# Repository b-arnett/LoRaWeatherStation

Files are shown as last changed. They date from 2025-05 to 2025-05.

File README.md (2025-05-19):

# LoRaWeatherStation
## Raspberry Pi Pico 2 based, automated solar-powered weather station and 'smart' home.



This repository contains code, STL cad files, notes, and pictures for a Remote weather station and 'smart' home that I designed.  This project operates on Raspberry Pi Pico 2s and uses RYLR993 lite LoRa modules for the communication method between the weather station and model house.  The use of these modules is pretty simple with the use of AT+ commands and initial range tests showed 1000+ feet in urban environment, and 1500 feet in a rural area with strong signal strength.   

## Repo 'map'
### Each system has Code and CAD subfolders for related content

- WeatherStation folder contains all code associated with the Weather Station.  WSMainSend.py is the finalized, tested and working code.  Other files are test programs.
- SmartHouse folder contains all code associated with the Smart House.  ModelComplete.py is the finalized, tested and working code.  Other files are test programs.
- LoRaTests folder contains test code for the using RYLR993 lite lora modules with CircuitPython.
- Documents contains pictures, notebook scans, and other documentation accumulated during this projects development.
- WebServer folder has code and cad files for the additional, SeeedStudio Xiao ESP32C6 based web server that hosts a simple stats page and graph.     

### Example of how the web server displays
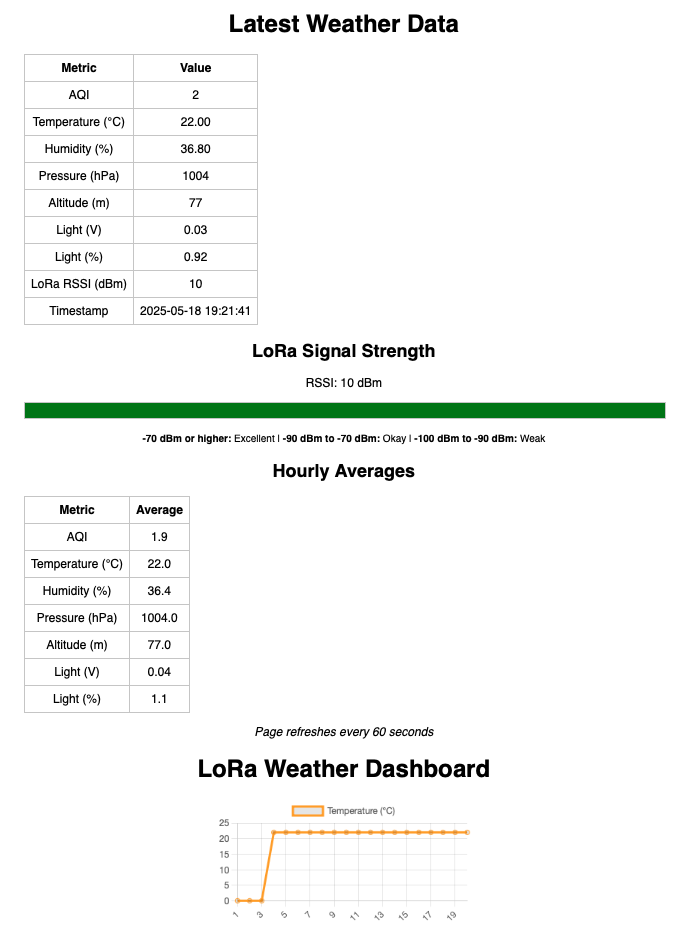
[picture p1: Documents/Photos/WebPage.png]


### To be added:
- Commenting on test programs
- Additional project documentation

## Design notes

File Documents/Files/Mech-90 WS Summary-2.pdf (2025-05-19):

Mech-0090 | Ben Arnett

### Project Summary

Issues
The first issue I encountered was converting code from MicroPython to CircuitPython. Adafruit provides CircuitPython libraries to use with a lot of their products, and for ease of use I decided to make the switch from MicroPython. While both were similar, the manner in which GPIO pins and libraries are used felt noticeably different and took some time to get used to and convert code properly. Another relatively big issue was that I prioritized the development of the Weather Station side while incrementally testing parts of the Smart House. Every component worked when individually testing them, but by the time I was testing all of the Smart House actuators together I had power supply issues due to oversight by using a standard 5V 1A outlet. With a servo, LEDs, LCD, and motor connected, the power supply was insufficient so I opted to remove the motor to prioritize getting everything else properly functioning and built. This was a huge “how did I miss that” moment and while I could have added an internal battery, it would take away from the simplicity of just plugging in a USB-C cable. With that– as it stands the measured light is the only parameter that changes physical states of the Smart Homes’ actuators (LEDs, shutters).

Unique Features
The primary unique feature employed was the use of LoRa wireless data transmission. When most people think of wireless communication, the first things that come to mind are WiFi, Bluetooth, and cellular. While these provide high bandwidths, they come at the cost of range and power consumption. As IoT (Internet of Things) devices are becoming more and more prevalent, LoRa provides an elegant solution for long range, low-power applications. While the amount of data it can transfer at a time is limited (256 bytes at a time), this is more than sufficient for applications like relaying sensor data or short messages.
Another unique feature is that the system pair is completely automated other than the need to supply / connect power. Once the solar station is up, it takes care of itself and intermittently reads and sends weather data. The Smart house, on the other hand, waits for weather data and automatically adjusts the interior controls.
One last unique feature that I added last minute was a standalone LoRa receiver and website host. This keychain-sized package is set up to connect to my phone's hotspot and host a website that displays the latest received weather data as well as the average data for the last hour. This bit runs on a SeeedStudio Xiao-ESP32C6, which has an incredibly small footprint in addition to WiFi and Bluetooth capability. Had I learned about this uC prior to starting this project, I would have likely chosen another

Mech-0090 | Ben Arnett

small form-factor board from SeeedStudio’s Xiao line of uC’s. I primarily used vibe coding (AI prompted coding) to program this, as I have no prior experience with programming on Arduino IDE with C/C++ and this was an extra system that I was curious to see if I could add to the project.

Future Changes
As far as changes I would make, it primarily boils down to the Weather Station housing. I would like to spend more time looking into different ways of making it rain-proof while still allowing for good airflow through the system. One downside of having the solar panels mounted on the roof was that it noticeably increased the temperature inside the station due to them being a dark color and absorbing heat from the sun. Another contributor to this temperature increase was likely insufficient air flow going through the station. Another “quality of life” improvement I’d make would be to adjust how the station pieces connect to each other– because of the design of how everything comes together it becomes a time consuming task for even just connecting the power inside. To go with that, the addition of a waterproof switch would make the process of turning on the station much easier.
I also want to redesign the power supply of the model house in order to use a motor for a fan. This would also allow for additional physical state changes based on things like temperature and humidity.
Further changes would be integrating the Smart Home with the internet, and LoRaWAN in general. This would make the stations’ data available from anywhere in the world, and truly make it an Internet of Things device. To go with that, adding a website host/handler directly to the smart home would be ideal instead of another separate device.

Total Cost: $496.26

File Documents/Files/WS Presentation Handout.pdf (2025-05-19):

Mech-0090 | Ben Arnett

### Weather Station and Smart Home

Project Goal:
1. Create a solar-powered, weather data acquisition system that wirelessly transmits collected data.
2. Make a smart home that receives weather data, and automatically adjusts “interior climate” settings.
How it works:
The wireless communication between systems is accomplished using LoRa, or Long Range data transmission. LoRa is a communication method that lets ‘small’ devices talk over long distances (miles with a good line of sight) and uses very little power. The weather station measures temperature, relative humidity, pressure, ambient light, particulate matter, and gas VOC. The smart home then displays the more ‘desirable’ data on an LCD character display and adjusts its interior lights and shutters.

Microcontroller / Language:
Raspberry Pi Pico 2 for UART pins to use Reyax RYLR LoRa modules with. CircuitPython. Simplified code walkthrough:
Weather Station: Read equipped sensors and format measurement values. Process those values into a formatted string, so the model house can parse the data. Send that formatted string using LoRa wireless data transmission. Go to sleep for a while, the weather typically changes at a ‘slow’ rate. Smart Home: Upon POR, modulate LEDs and Shutter servo to show they work. Wait for incoming data. Extract the payload from the incoming data string. Parse the payload into a dictionary (key:value pairs) so that it can act on the data. Change the LEDs and Shutter position. Update the LCD to display temperature, relative humidity, AQI, and light percentage. Continue waiting for incoming data. Issues encountered:
Power supply issues with the smart house– removed fan function due to time constraints. Converting code from MicroPython to CircuitPython and to that extent– learning another programming language.

Unique Features:
Complete automation– the only human interaction needed is to ‘plug it in’. Intelligent data manipulation for actuator adjustments. The use of LoRa communication, measured ranges of 1500+ feet in a rural area while still having strong signal strength. Additional device that hosts a website for weather data, showing latest data, hour averages, and a temperature chart.

Cost: $496.46
Github Repo:

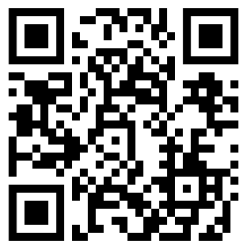
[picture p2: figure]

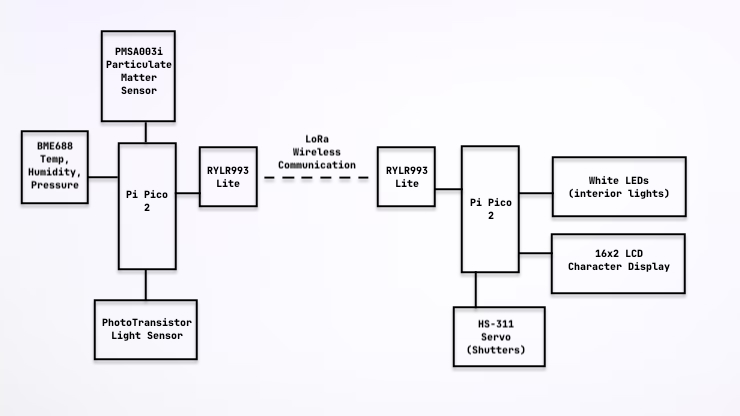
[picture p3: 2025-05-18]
Documents/Files/BlockDiagramWS.jpg

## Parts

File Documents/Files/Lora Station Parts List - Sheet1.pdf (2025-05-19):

Lora Weather Station Parts List | Ben Arnett | 05/18/25
Quantity | Description | Dist. Part No | Price Ea. | Extended Cost Running Total | Product Link | Datasheet / Reference Link

2

| Rylr993 Lora Module w/
antenna | B0B9XQ2822 | $23.00 | $46.00 | $92.00 https://www.amazon.com/REYAX-RYLR998-Interface-Antenna-Transceiver/dp/B099RM1XMG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 https://reyax.com/products/RYLR993_Lite
3 Raspberry Pi Pico 2 | 6006 | $5.00 | $15.00 | $107.00 https://www.adafruit.com/product/6006 | https://datasheets.raspberrypi.com/pico/pico-2-datasheet.pdf
| 3 5v 1.2W solar panels | 5368 | $14.95 | $44.85 | $151.85 https://www.adafruit.com/product/5368

1

| BME688 - Temp, Humidity,
| Pressure, VOC | 5046 | $19.95 | $19.95 | $171.80 https://www.adafruit.com/product/5046
1 PMSA003i Air Quality Breakout 4632 | $44.95 | $44.95 | $216.75 https://www.adafruit.com/product/4632 | https://cdn-shop.adafruit.com/product-files/4632/4505_PMSA003I_series_data_manual_English_V2.6.pdf
1 Solar Charge Controller | B07MML4YJV | $13.90 | $13.90 | $230.65 https://www.amazon.com/gp/product/B07MML4YJV/ref=ewc_pr_img_2?smid=A2EH5PO307BR7O&psc=1 https://wiki.dfrobot.com/Solar_Power_Manager_5V_SKU__DFR0559
1 5200mAh LIon Battery 3.7v | B0CP7M4MY1 | $15.49 | $15.49 | $246.14 https://www.amazon.com/gp/product/B0CP7M4MY1/ref=ppx_yo_dt_b_asin_title_o00_s00?ie=UTF8&th=1
1 440pc M3 screw set | B0BMQFHDBH | $9.99 | $9.99 | $256.13 https://www.amazon.com/gp/product/B0BMQFHDBH/ref=ewc_pr_img_5?smid=AZGB5J3DWE4QP&th=1
2 Photo Transistor | 2831 | $0.95 | $1.90 | $258.03 https://www.adafruit.com/product/2831 | https://cdn-shop.adafruit.com/product-files/2831/HW5P-1_2015__1_.pdf
| 1 Pico Terminal PiCowbell | 5907 | $12.50 | $12.50 | $270.53 https://www.adafruit.com/product/5907

1

| 22ga Solid core hookup wire
set | B09BFFJRST | $16.99 | $16.99 | $287.52 https://www.amazon.com/gp/product/B09BFFJRST/ref=ox_sc_act_title_2?smid=AMHYOXF0C8EDF&th=1
1 M/F pin header kit | B0B973QQ8P | $9.99 | $9.99 | $297.51 https://www.amazon.com/Ruibapa-Connector-Assortment-Breakaway-P-037-Kit/dp/B0B973QQ8P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
1 Solder 0.8mm 50g | B075WB98FJ | $7.19 | $7.19 | $304.70 https://www.amazon.com/gp/product/B075WB98FJ/ref=sw_img_1?smid=A25N4YN27ERTBB&th=1
1 M3 Threaded Heat Inserts | B09MTRHBRL | $10.99 | $10.99 | $315.69 https://www.amazon.com/gp/product/B09MTRHBRL/ref=ox_sc_saved_title_5?smid=A2L1PKBL5IWW8M&th=1
1 1kg PETG Filament | 33100 | 19.99 | 19.99 | $335.68 https://us.store.bambulab.com/products/petg-hf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
1 Solderable Breadboards | B09X1CV9ST | 8.99 | 8.99 | $344.67 https://www.amazon.com/dp/B09X1CV9ST?ref=ppx_yo2ov_dt_b_fed_asin_title&th=1
1 USB-C Breakout Boards | B096M2HQLK | 8.99 | 8.99 | $353.66 https://www.amazon.com/dp/B096M2HQLK?ref=ppx_yo2ov_dt_b_fed_asin_title
1 White LEDs | B07DYWC9YT | 7.19 | 7.19 | $360.85 https://www.amazon.com/dp/B07DYWC9YT?ref=ppx_yo2ov_dt_b_fed_asin_title
1 HS-311 Servo | 2589-31311S-ND | 13.49 | 13.49 | $374.34 https://www.digikey.com/en/products/detail/hitec-commercial-solutions/31311S/12148509
1 16x2 LCD char. Display | B0D2L9JHLD | 8.99 | 8.99 | $383.33 https://www.amazon.com/Interface-Backlight-Controller-Raspberry-Tinkerboard/dp/B0D2L9JHLD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
1 Dupont Connector Kit | B01EV70C78 | 6.98 | 6.98 | $390.31 https://www.amazon.com/dp/B01EV70C78?ref=ppx_yo2ov_dt_b_fed_asin_title
1 Waterproofing Spray | 52130847 | 7.98 | 7.98 | $398.29 https://www.walmart.com/ip/V-I-P-Silicone-Water-Guard-Water-Repellent-13-13-Ounces/52130847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
1 SeeedStudio Xiao ESP32C6 | 113991254 | 5.2 | 5.2 | $403.49 https://www.seeedstudio.com/Seeed-Studio-XIAO-ESP32C6-p-5884.html
1 RYLR998 LoRa Module | B099RM1XMG | 12.6 | 12.6 | $416.09 https://www.amazon.com/REYAX-RYLR998-Interface-Antenna-Transceiver/dp/B099RM1XMG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
Tax + Shipping | $80.17 | $496.26

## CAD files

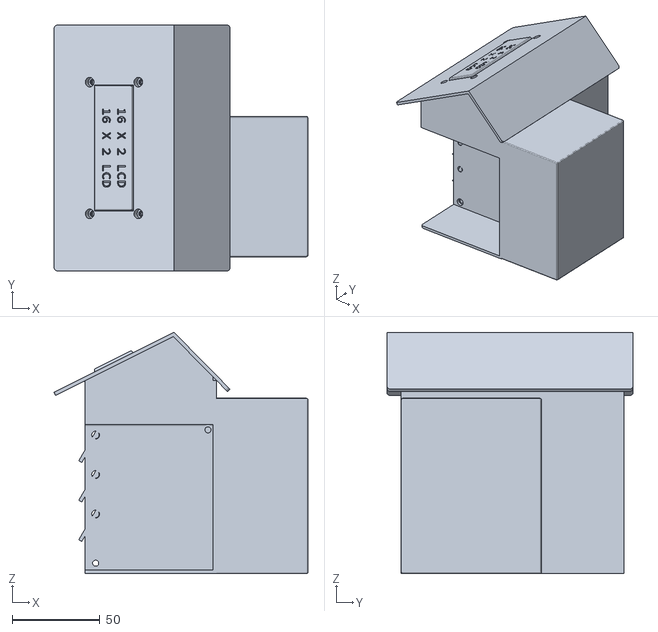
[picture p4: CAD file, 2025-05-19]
SmartHouse/CAD/ModelHouseAssembled.stl
144.7 x 140.0 x 137.6

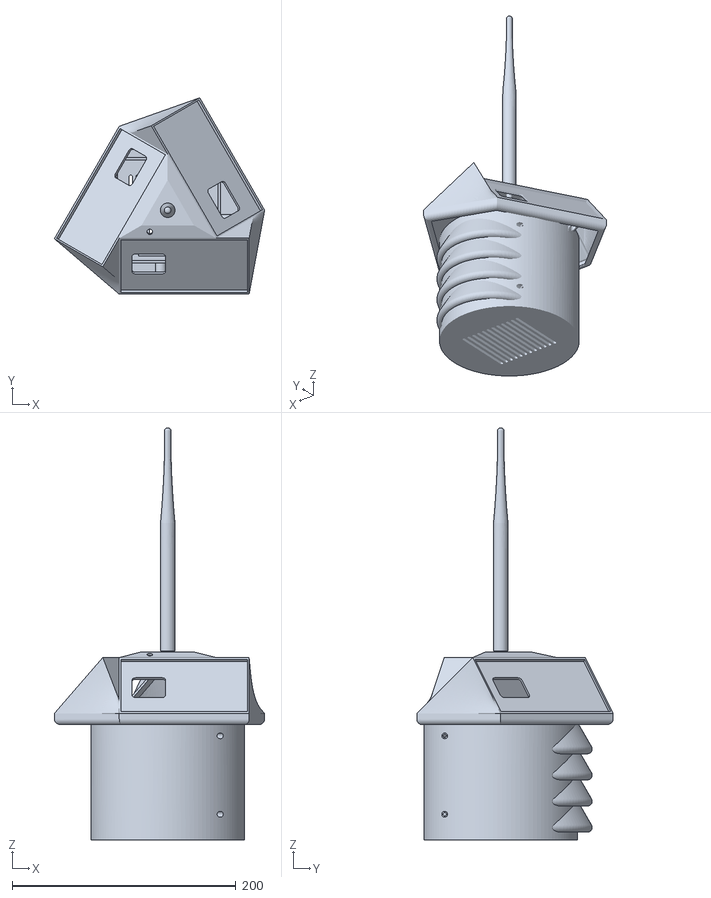
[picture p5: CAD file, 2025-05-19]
WeatherStation/CAD/WSAssembled.stl
187.9 x 175.5 x 368.0

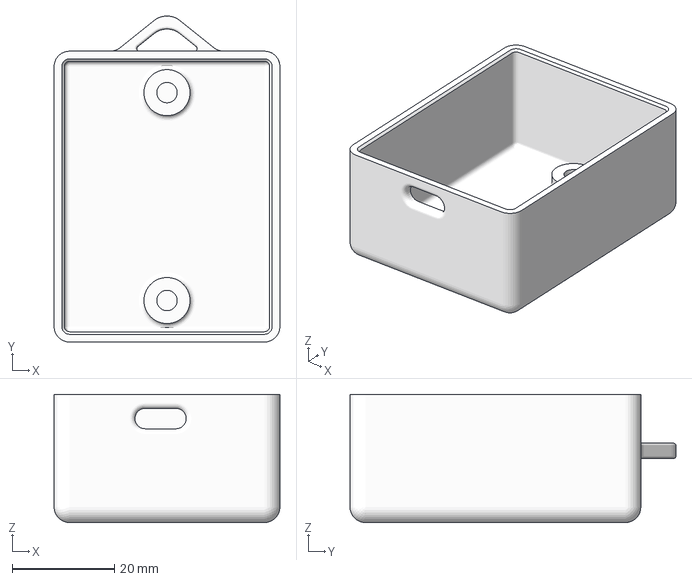
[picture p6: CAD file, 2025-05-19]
WebServer/CAD/XiaoBody.3mf
44.1 x 63.7 x 25.0 mm

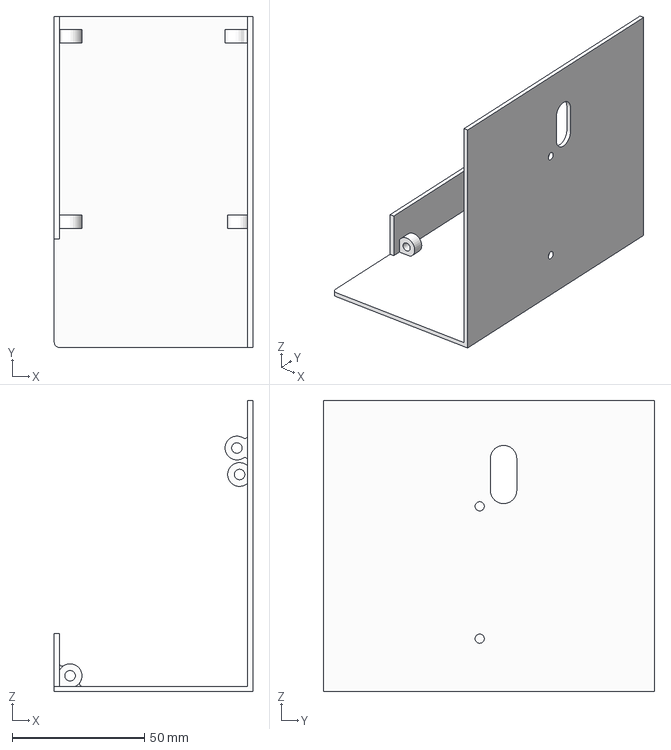
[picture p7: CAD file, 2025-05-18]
SmartHouse/CAD/ActBase.3mf
75.0 x 125.0 x 110.0 mm

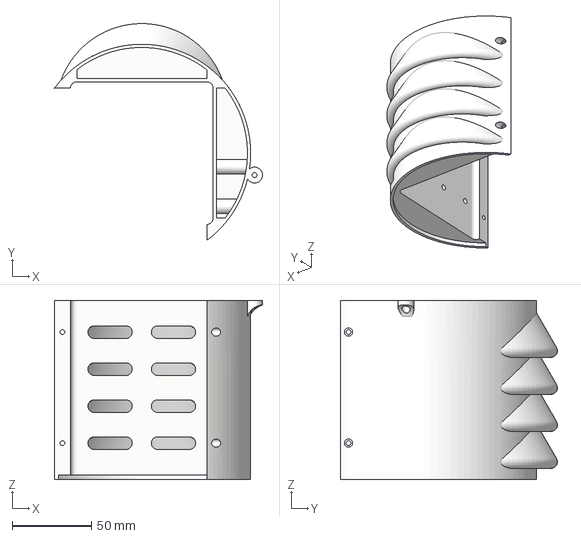
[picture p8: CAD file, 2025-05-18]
WeatherStation/CAD/WSBaseVent.3mf
131.2 x 136.8 x 113.0 mm

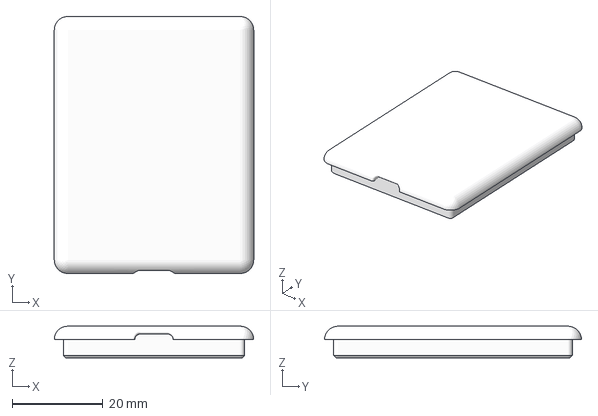
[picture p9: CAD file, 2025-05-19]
WebServer/CAD/XiaoTop.3mf
44.1 x 56.8 x 7.00 mm

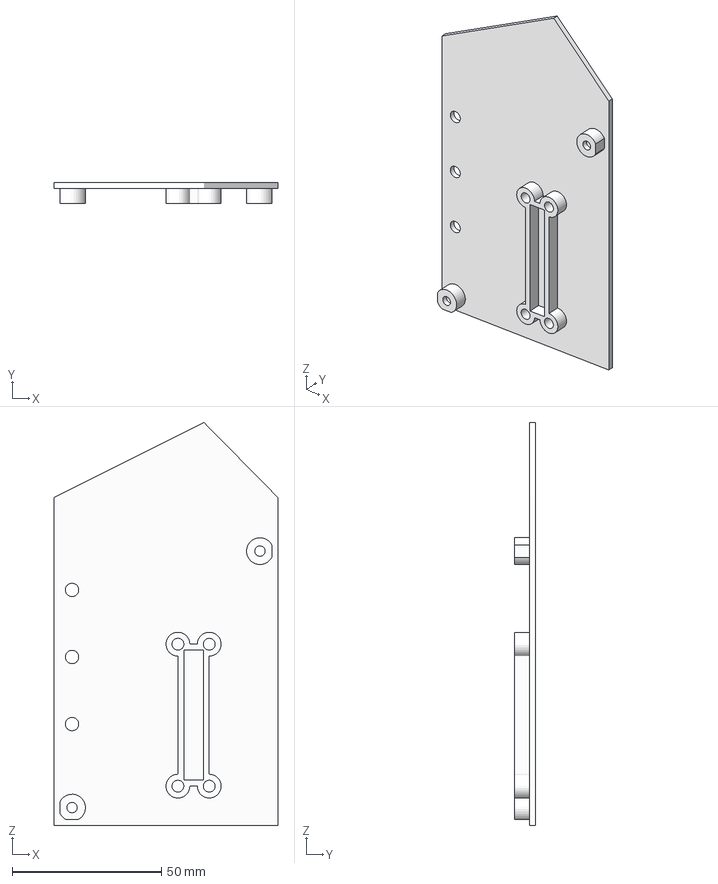
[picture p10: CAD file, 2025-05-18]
SmartHouse/CAD/AHSide.3mf
75.0 x 7.00 x 135.1 mm

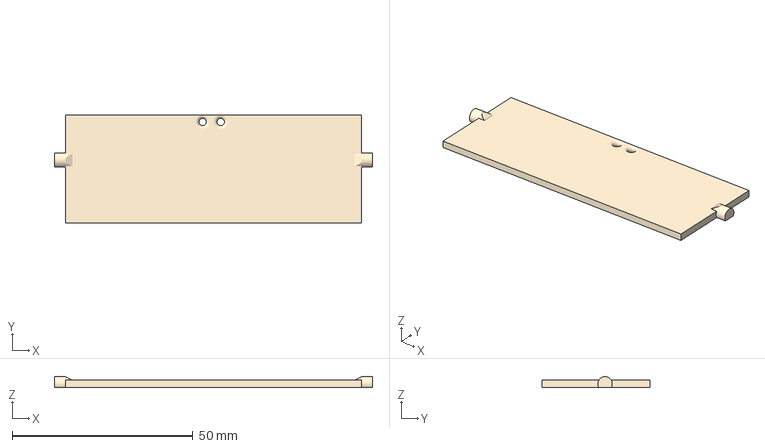
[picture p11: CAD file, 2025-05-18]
SmartHouse/CAD/ShutterPiece.3mf
88.0 x 30.0 x 3.00 mm

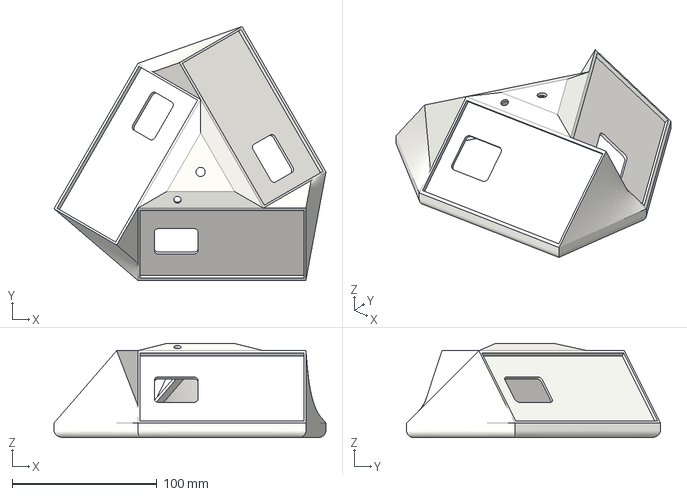
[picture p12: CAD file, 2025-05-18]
WeatherStation/CAD/WSTopRoof.3mf
187.9 x 175.5 x 65.0 mm

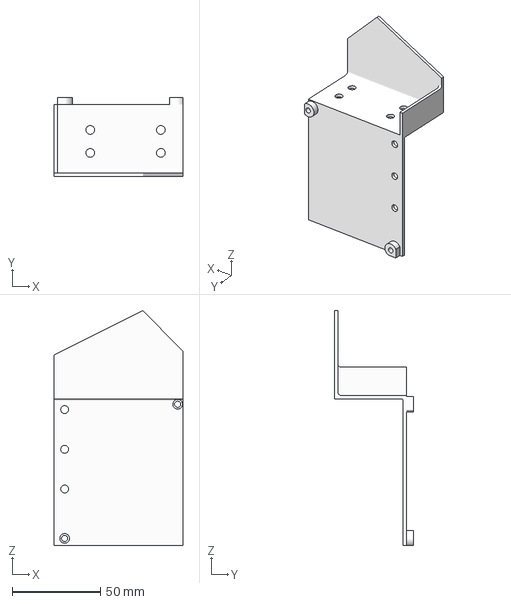
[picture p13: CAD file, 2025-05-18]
SmartHouse/CAD/LSide.3mf
73.0 x 45.0 x 133.1 mm

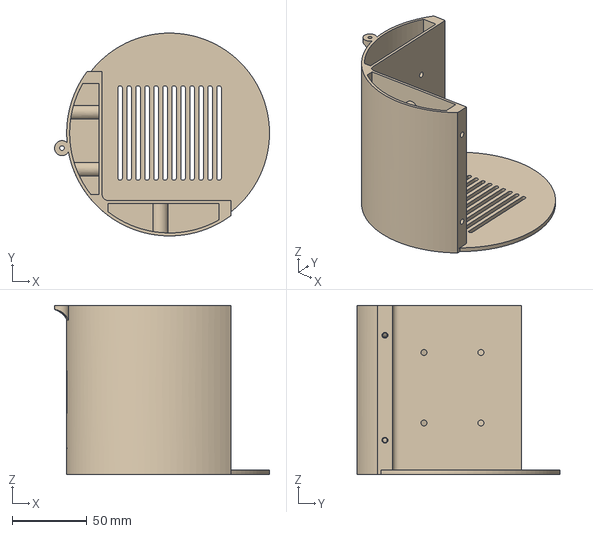
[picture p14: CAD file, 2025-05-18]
WeatherStation/CAD/WSBaseUC.3mf
143.4 x 135.3 x 113.0 mm

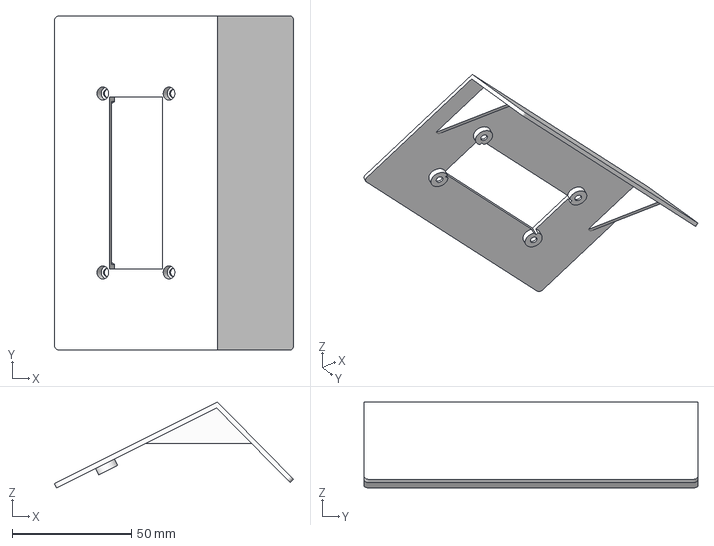
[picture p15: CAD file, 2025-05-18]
SmartHouse/CAD/Roof.3mf
100.3 x 140.0 x 36.0 mm

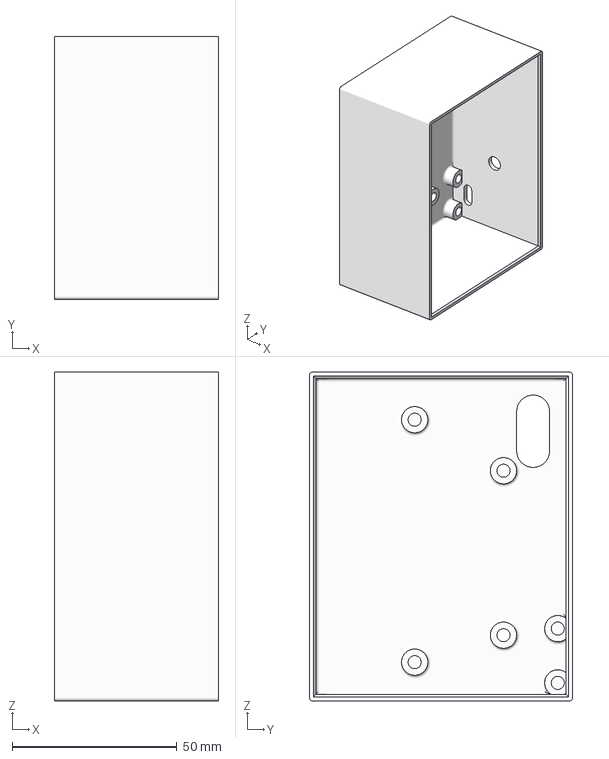
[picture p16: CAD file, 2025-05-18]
SmartHouse/CAD/ControlHousing.3mf
50.0 x 80.0 x 100.0 mm

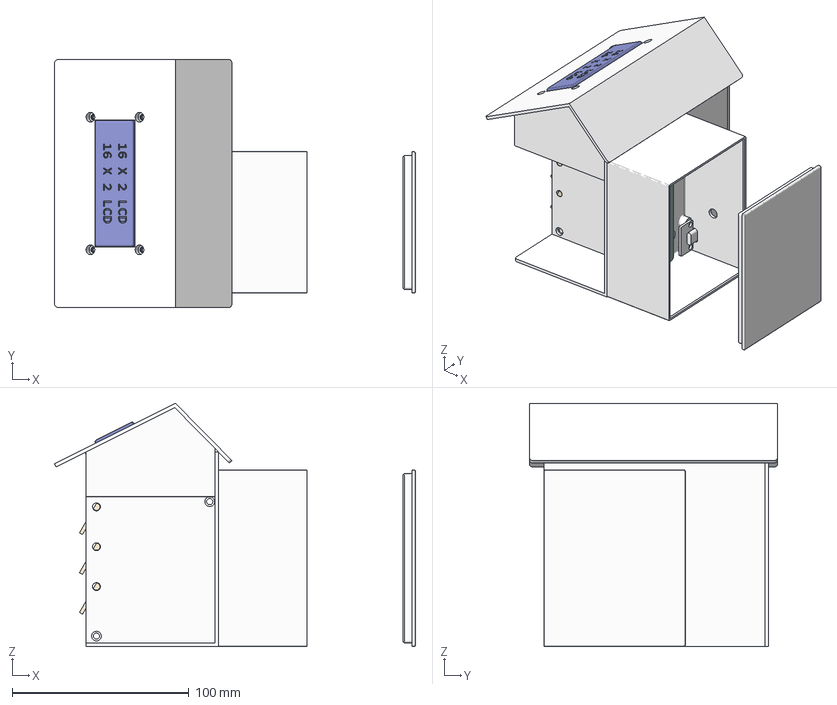
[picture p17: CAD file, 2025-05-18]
SmartHouse/CAD/Model_House_Rev_2 v15.3mf
204.0 x 140.0 x 137.6 mm

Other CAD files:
WeatherStation/CAD/WSComplete.3mf
SmartHouse/CAD/CHLid.3mf

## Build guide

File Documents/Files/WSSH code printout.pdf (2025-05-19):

# WSMainSend.py

# Ben Arnett

# 05/12/2025

import time
import board
import busio
import analogio
import adafruit_bme680
import digitalio
from digitalio import DigitalInOut, Direction, Pull from adafruit_pm25.i2c import PM25_I2C

reset_pin = None

# Setup IO pin to turn on and off PMSA03i pwr = digitalio.DigitalInOut(board.GP15) pwr.direction = digitalio.Direction.OUTPUT pwr.value = True

# Create library object, use 'slow' 100KHz frequency! i2c = busio.I2C(board.GP9, board.GP8, frequency=100000)

# Connect to a PMSA003i over I2C

pms = PM25_I2C(i2c, reset_pin) print("Found PMSA003i")

# Connect to BME688 over I2C

# note: BME688 uses the bme680 library sensor =

adafruit_bme680.Adafruit_BME680_I2C(i2c) sensor.seaLevelhPa = 1011
print("Found BME688")

# Init UART bus for RYLR993 lite

uart = busio.UART(board.GP0, board.GP1, baudrate=9600)
print("UART bus enabled")

# PhotoTransistor setup

pt = analogio.AnalogIn(board.GP26) print("Photo Transistor Found")

# Address of Rylr module to send to

address = 6

# Function to send LoRa messages with the RYLR def rylr_send(message):

length = len(message)
send = 'AT+SEND={},{},{}\r\n'.format(address, length, message)
uart.write(send.encode("ascii"))
print('Data sent to {}'.format(address))

# Function to apply AQI correction calculations def correct_pm25(pm25, humidity, temperature):

# correction calculations from ChatGPT

# Humidity correction (EPA formula) humidity_correction = 1 + 0.487 * (2.718 ** (0.059 * humidity))

pm25_corrected = pm25 / humidity_correction

# Temperature correction

temp_correction_factor = 1 - 0.02 * (temperature -25)
pm25_corrected *= temp_correction_factor

return pm25_corrected

# Get Light sensor voltage

def ptvoltage(adcin):
steps = 0
i = 0
# get average over 4 seconds while i < 20:

steps += adcin.value
time.sleep(0.2)
i += 1

steps = steps/20

# Pico ADC is 12 bits, so need to scale to 16 bits to work with CircuitPython's API

return (steps * 3.3) / 65536

# Main Loop

while True:
# Turn on PMSA, give 30s to warmup pwr.value = True

print("Turned on PMSA, 30s warmup") time.sleep(30)
print("Reading Sensors")

try:
aqdata = pms.read()
# print(aqdata)

except RuntimeError:
print("Unable to read from sensor, retrying...") continue

# get raw PM 2.5 concentration and apply corrections

pms_data = pms.read()
pm25_raw = pms_data["pm25 standard"] pm25_corrected = correct_pm25(pm25_raw, humidity, temperature)

# get BME688 sensor data

humidity = sensor.relative_humidity temperature = sensor.temperature pressure = sensor.pressure altitude = sensor.altitude

# get PhotoTransistor Voltage

ptvolt = ptvoltage(pt)

# Apply significant figures

pm25_corrected = round(pm25_corrected) humidity = "{:2.1f}".format(humidity) temperature = round(temperature) # 3 Digits pressure = round(pressure) #
altitude = round(altitude)
ptvolt = "{:1.2f}".format(ptvolt) # 3 dig. 4 char

# format to be parse-able

rylrmsg =
'AQI:{0};T:{1};RH:{2};hPa:{3};Alt:{4};L:{5}'.format(pm2 5_corrected, temperature, humidity, pressure, altitude, ptvolt)
rylr_send(rylrmsg)
print(rylrmsg)

# Turn off PMSA

pwr.value = False
print("Turned off PMSA, light sleeping")
# Light sleep till next reading time.sleep(866) # Sleep 14m 26s (15 mins between data transmissions)

# ^ account for 30s PMSA on time & 4s light volt reading

# ModelComplete.py

# Ben Arnett

# 05/12/2025

# UART = GP 0,1

# I2C = SDA-GP8, SCL-GP9

# Led PWM = GP5

# Servo PWM = GP28

import board
import busio
import digitalio
import time
import pwmio
from lcd1602 import LCD1602
from adafruit_motor import servo

# Initialize Devices

rylr = busio.UART(board.GP0, board.GP1, baudrate=9600)
i2c0 = busio.I2C(board.GP9, board.GP8, frequency=100000)

lcd = LCD1602(i2c0)
lcd.clear()
lcd.write(' Initializing')

whtled = pwmio.PWMOut(board.GP3, frequency=5000, duty_cycle=0) servo_a_pin = pwmio.PWMOut(board.GP28, frequency=50)
servo_a = servo.Servo(servo_a_pin, min_pulse=1000, max_pulse=2000)

# 'Breathe' leds once, modulate servo to verify function

for i in range(100):
if i < 50:
whtled.duty_cycle = int(i * 2 * 65535 / 100) # Up
else:
whtled.duty_cycle = 65535 - int((i - 50) * 2 * 65535 / 100) # Down
time.sleep(0.025)

whtled.duty_cycle = 0

servo_a.angle = 0
time.sleep(0.5)
servo_a.angle = 20
time.sleep(0.5)
servo_a.angle = 40
time.sleep(0.5)
servo_a.angle = 60
time.sleep(0.5)
servo_a.angle = 70
time.sleep(0.5)

lcd.clear()
lcd.set_cursor(2, 0)
lcd.write('Waiting for')
lcd.set_cursor(2, 1)
lcd.write('Weather Data')
print("Init complete, waiting for data")

recieved = False

# Function to parse new recieved data

# Modified for circuitpython from https://github.com/TimHanewich/MicroPython-Collection/blob/master/REYAX-RYLR998/

def parse_sensor_data(data: str) -> dict:
# Extract the weather data from entire recieved byte data

result = {}
address:int = None # the address of the transmitter it came from
length:int = None # the length (number of bytes) of the data payload
msg:bytes = None # the payload data itself RSSI:int = None # Received signal strength indicator
SNR:int = None # Signal-to-noise ratio

try:
# find landmarkers that will help with parsing i_equal:int = data.find("=")

i_comma1:int = data.find(",")

i_comma2:int = data.find(",", i_comma1 + 1) i_comma4:int = data.rfind(",") # search from end
i_comma3:int = data.rfind(",", 0, i_comma4-1) # search for a comma from right, starting at 0 and ending at the last comma (or right before it)
# i_linebreak:int = data.find("\r\n")

# extract

ReceivedMessage = data
address = int(data[i_equal + 1:i_comma1]) length = int(data[i_comma1 + 1:i_comma2]) msg = data[i_comma2 + 1:i_comma3] RSSI = int(data[i_comma3 + 1:i_comma4]) #SNR = int(data[i_comma4 + 1:i_linebreak]) except Exception as e:
raise Exception("Unable to parse line '" + str(data) + "' as a ReceivedMessage! Exception message: " + str(e))

# Take the weather data string and turn into a dictionary

# Modified from ChatGPT generated code pairs = msg.split(";") # Split the string into key-value pairs

for pair in pairs:
if ":" in pair:
key, value = pair.split(":") # Separate key and value
# Try to convert value to int or float if possible

if value.replace(".", "", 1).isdigit():
value = float(value) if "." in value else int(value)
result[key] = value
return result # returns a dictionary

# Function to change interior conditions

def interior(d):
light = d['L']
# If its pretty bright, open blinds and turn off lights if light > 3:

whtled.duty_cycle = 0
servo_a.angle = 15
return

involt = 3 - light
lightduty = round(involt * 18000) # inverted scaling servangle = round(18 * involt) + 15 # regular scaling

print('lightduty = {0} servangle = {1}'.format(lightduty, servangle))

whtled.duty_cycle = lightduty servo_a.angle = servangle
return

# Function to update stats on display def lcddisplay(d):

if recieved == False:
lcd.clear()
lcd.write('T: C Light: %') lcd.set_cursor(0, 1)
lcd.write('AQI: RH: %')

lightperc = round(d['L'] / 3.2 * 100)

lcd.set_cursor(2, 0)
if d['T'] < 10:
lcd.write(" ")
lcd.write(str(d['T']))
lcd.set_cursor(12, 0)
lcd.write(lcdform(lightperc)) lcd.set_cursor(4, 1)
lcd.write(lcdform(d['AQI'])) lcd.set_cursor(11, 1)
lcd.write(str(lcdform(round(d['RH'])))) return
# T:00C Light:00%

# _AQI:000 RH:00%

# Format data to write properly def lcdform(number):

stringout = ""
if number < 10:
stringout = stringout + " "
elif number < 100:
stringout = stringout + " " stringout = stringout + str(number) return stringout

# Main Loop

while True:
data = rylr.read()

if data is not None:
# Make a string with incoming data, then put it through the parser

data_string = ''.join([chr(b) for b in data]) print(data_string, end="")
parsed = parse_sensor_data(data_string) print(parsed)

# Update display and Interior settings lcddisplay(parsed)

interior(parsed)
recieved = True

else:
if recieved == False:
time.sleep(0.05)

Test Codes:
Reyax RYLR Lora Module Tests: # RYLR Receive test
import board
import busio
import digitalio
import time

led = digitalio.DigitalInOut(board.LED) led.direction = digitalio.Direction.OUTPUT

uart = busio.UART(board.GP0, board.GP1, baudrate=9600)

while True:
data = uart.read()

if data is not None:
led.value = True
data_string = ''.join([chr(b) for b in data]) print(data_string, end="")

led.value = False

else:

print("waiting")
time.sleep(0.05)

# RYLR send test

import board
import busio
import digitalio
import time

uart = busio.UART(board.GP0, board.GP1, baudrate=9600)
test = 0
send = "AT+SEND=6,4,test\r\n"

led = digitalio.DigitalInOut(board.LED) led.direction = digitalio.Direction.OUTPUT ledState = False

while True:
led.value = True

uart.write(send.encode("ascii")) print("sent")
time.sleep(2.5)
led.value = False
time.sleep(2.5)

# Rylr993RangeTest.py

# Ben Arnett

# 03/04/25

import time
import board
import busio
import digitalio

# Only use with Rylr993 lite, not 998

rylr = busio.UART(board.GP0, board.GP1, baudrate=9600)

# address of Rylr on network to send to addr = 27

led = digitalio.DigitalInOut(board.LED) led.direction = digitalio.Direction.OUTPUT

i = 1

while True:
led.value = True
msg = "Test " + str(i)
length = len(msg)
send = 'AT+SEND={},{},{}\r\n'.format(addr, length, msg)

rylr.write(send.encode("ascii")) print("Just sent test " + str(i))
led.value = False
time.sleep(5)
i += 1

Weather Station Test code

# BME688 Test from Adafruit

import board
import busio
import adafruit_bme680
import time

i2c = busio.I2C(board.GP9, board.GP8) sensor =
adafruit_bme680.Adafruit_BME680_I2C(i2c)

sensor.seaLevelhPa = 1011

while True:

print('Temperature: {} degrees C'.format(sensor.temperature))
print('Gas: {} ohms'.format(sensor.gas)) print('Humidity: {}%'.format(sensor.humidity)) print('Pressure:
{}hPa'.format(sensor.pressure)) print('Altitude: {}
meters'.format(sensor.altitude)) print("---------------------------------") time.sleep(1)

# PMSA003i test from Adafruit

# SPDX-FileCopyrightText: 2021 ladyada for Adafruit Industries

# SPDX-License-Identifier: MIT

"""
Example sketch to connect to PM2.5 sensor with either I2C or UART.
"""

# pylint: disable=unused-import

import time
import board
import busio
import adafruit_bme680
from digitalio import DigitalInOut, Direction, Pull from adafruit_pm25.i2c import PM25_I2C

reset_pin = None
# If you have a GPIO, its not a bad idea to connect it to the RESET pin

# reset_pin = DigitalInOut(board.G0)

# reset_pin.direction = Direction.OUTPUT # reset_pin.value = False

# For use with a computer running Windows: # import serial

# uart = serial.Serial("COM30", baudrate=9600, timeout=1)

# For use with microcontroller board:

# (Connect the sensor TX pin to the board/computer RX pin)

# uart = busio.UART(board.TX, board.RX, baudrate=9600)

# For use with Raspberry Pi/Linux:

# import serial

# uart = serial.Serial("/dev/ttyS0", baudrate=9600, timeout=0.25)

# For use with USB-to-serial cable: # import serial

# uart = serial.Serial("/dev/ttyUSB0", baudrate=9600, timeout=0.25)

# Connect to a PM2.5 sensor over UART

# from adafruit_pm25.uart import PM25_UART # pm25 = PM25_UART(uart, reset_pin)

# Create library object, use 'slow' 100KHz frequency!

i2c = busio.I2C(board.GP9, board.GP8, frequency=100000)
# Connect to a PM2.5 sensor over I2C pm25 = PM25_I2C(i2c, reset_pin)

sensor =
adafruit_bme680.Adafruit_BME680_I2C(i2c)

sensor.seaLevelhPa = 1011

print("Found PM2.5 sensor, reading data...")

while True:
time.sleep(1)

try:
aqdata = pm25.read()
# print(aqdata)

except RuntimeError:
print("Unable to read from sensor, retrying...")
continue

print()
print("Concentration Units (standard)") print("---------------------------------------") print(
"PM 1.0: %d\tPM2.5: %d\tPM10: %d" % (aqdata["pm10 standard"], aqdata["pm25 standard"], aqdata["pm100 standard"])
)
print("Concentration Units (environmental)") print("---------------------------------------")
print(
"PM 1.0: %d\tPM2.5: %d\tPM10: %d"
% (aqdata["pm10 env"], aqdata["pm25 env"], aqdata["pm100 env"])
)
print("---------------------------------------") print("Particles > 0.3um / 0.1L air:", aqdata["particles 03um"])
print("Particles > 0.5um / 0.1L air:", aqdata["particles 05um"])
print("Particles > 1.0um / 0.1L air:", aqdata["particles 10um"])
print("Particles > 2.5um / 0.1L air:", aqdata["particles 25um"])
print("Particles > 5.0um / 0.1L air:", aqdata["particles 50um"])
print("Particles > 10 um / 0.1L air:", aqdata["particles 100um"]) print("---------------------------------------")

print('Temperature: {} degrees C'.format(sensor.temperature))
print('Gas: {} ohms'.format(sensor.gas)) print('Humidity: {}%'.format(sensor.humidity))

print('Pressure:
{}hPa'.format(sensor.pressure)) print('Altitude: {}
meters'.format(sensor.altitude)) print("---------------------------------")

# AQI with BME688 based correction factors # From ChatGPT, with adjustments made by Ben A.

import time
import board
import busio
import adafruit_bme680 # Works for BME688 too
import adafruit_pm25
from digitalio import DigitalInOut, Direction, Pull from adafruit_pm25.i2c import PM25_I2C

# Initialize I2C communication and the PMSA003I sensor

i2c = busio.I2C(board.GP9, board.GP8, frequency=100000)
# Connect to a PM2.5 sensor over I2C pms = PM25_I2C(i2c)

# Initialize BME688 sensor

bme =
adafruit_bme680.Adafruit_BME680_I2C(i2c)

def correct_pm25(pm25, humidity, temperature):
"""
Applies correction factors to PM2.5 based on humidity and temperature.

Args:
pm25 (float): Raw PM2.5 measurement (µg/m³)
humidity (float): Relative humidity (%) temperature (float): Temperature (°C)

Returns:
float: Corrected PM2.5 value
"""
# Humidity correction (EPA formula)

humidity_correction = 1 + 0.487 * (2.718 ** (0.059 * humidity))
pm25_corrected = pm25 /
humidity_correction

# Temperature correction

temp_correction_factor = 1 - 0.02 * (temperature - 25)
pm25_corrected *= temp_correction_factor

return pm25_corrected

while True:
# Read sensor data

pms_data = pms.read()
pm25_raw = pms_data["pm25 standard"]

humidity = bme.relative_humidity temperature = bme.temperature

# Apply correction

pm25_corrected = correct_pm25(pm25_raw, humidity, temperature)

# Print results

print(f"PM2.5 Raw: {pm25_raw:.2f} µg/m³") print(f"PM2.5 Corrected:
{pm25_corrected:.2f} µg/m³") print(f"Temperature: {temperature:.2f} °C, Humidity: {humidity:.2f} %")
print("-" * 40)

time.sleep(10)

# AQI with BME688 based correction factors # From ChatGPT, with adjustments made by Ben A.

import time
import board
import busio
import adafruit_bme680 # Works for BME688 too
import adafruit_pm25
from digitalio import DigitalInOut, Direction, Pull from adafruit_pm25.i2c import PM25_I2C

# Initialize I2C communication and the PMSA003I sensor

i2c = busio.I2C(board.GP9, board.GP8, frequency=100000)
# Connect to a PM2.5 sensor over I2C pms = PM25_I2C(i2c)

# Initialize BME688 sensor

bme =
adafruit_bme680.Adafruit_BME680_I2C(i2c)

def correct_pm25(pm25, humidity, temperature):
"""
Applies correction factors to PM2.5 based on humidity and temperature.

Args:
pm25 (float): Raw PM2.5 measurement (µg/m³)
humidity (float): Relative humidity (%) temperature (float): Temperature (°C)

Returns:
float: Corrected PM2.5 value
"""
# Humidity correction (EPA formula) humidity_correction = 1 + 0.487 * (2.718 ** (0.059 * humidity))

pm25_corrected = pm25 /
humidity_correction

# Temperature correction

temp_correction_factor = 1 - 0.02 * (temperature - 25)
pm25_corrected *= temp_correction_factor

return pm25_corrected

while True:
# Read sensor data

pms_data = pms.read()
pm25_raw = pms_data["pm25 standard"]

humidity = bme.relative_humidity temperature = bme.temperature

# Apply correction

pm25_corrected = correct_pm25(pm25_raw, humidity, temperature)

# Print results

print(f"PM2.5 Raw: {pm25_raw:.2f} µg/m³") print(f"PM2.5 Corrected:
{pm25_corrected:.2f} µg/m³") print(f"Temperature: {temperature:.2f} °C, Humidity: {humidity:.2f} %")
print("-" * 40)

time.sleep(10)

# ADC test for photo transistor # BA 03/11/25

import time
import busio
import board
import analogio

ptr = analogio.AnalogIn(board.GP26)

# Pico ADC is 12 bits, so need to scale to 16 bits to work with CircuitPython's API

def stepstovolt(step):
return (step * 3.3) / 65536
# | 2^16

while True:
steps = ptr.value
| voltage = stepstovolt(steps)
| print('Steps: {} Voltage: {:1.3}'.format(steps,
voltage))
time.sleep(0.5)

Smart Home Test Code

# Servo Test

# from Adafruit

from time import sleep
import board

import pwmio
from adafruit_motor import servo

DEBUG = True

servo_a_pin = pwmio.PWMOut(board.GP18, frequency=50)
servo_a = servo.Servo(servo_a_pin, min_pulse=1000, max_pulse=2000)
def basic_operations():
if DEBUG: print("Setting angle to 90 degrees.")
servo_a.angle = 90
sleep(3)
if DEBUG: print("Setting angle to 0 degrees.") servo_a.angle = 0
sleep(3)
if DEBUG: print("Setting angle to 90 degrees.")
servo_a.angle = 90
sleep(3)
if DEBUG: print("Setting angle to 180 degrees.")
servo_a.angle = 180
sleep(3)
while True:
basic_operations()

# PWM Led Test

# Ben Arnett

# 04/10/2025

import time
import board
import pwmio

redled = pwmio.PWMOut(board.GP3, frequency=5000, duty_cycle=0) #grnled = pwmio.PWMOut(board.GP17, frequency=5000, duty_cycle=0)

while True:
for i in range(100):
if i < 50:
redled.duty_cycle = int(i * 2 * 65535 /
100) # Up

#grnled.duty_cycle = 65535 - int(i * 2 * 65535 /100) # Down

else:
redled.duty_cycle = 65535 - int((i - 50) * 2 * 65535 / 100) # Down
#grnled.duty_cycle = int((i-50) * 2 * 65535 / 100) # Up

time.sleep(0.05)

# Receive, parse data test

import board
import busio
import digitalio
import time
from lcd1602 import LCD1602

led = digitalio.DigitalInOut(board.LED) led.direction = digitalio.Direction.OUTPUT

uart = busio.UART(board.GP0, board.GP1, baudrate=9600)
i2c = busio.I2C(board.GP9, board.GP8, frequency=100000)
lcd = LCD1602(i2c)

# Modified for circuitpython from https://github.com/TimHanewich/MicroPython-Collection/blob/master/REYAX-RYLR998/ (https://github.com/TimHanewich/MicroPython-Collection/blob/master/REYAX-RYLR998/)

def parse_sensor_data(data: str) -> dict: result = {}
address:int = None # the address of the transmitter it came from
length:int = None # the length (number of bytes) of the data payload
msg:bytes = None # the payload data itself RSSI:int = None # Received signal strength indicator
SNR:int = None # Signal-to-noise ratio

try:

# find landmarkers that will help with parsing

i_equal:int = data.find("=") i_comma1:int = data.find(",") i_comma2:int = data.find(",", i_comma1 + 1)
i_comma4:int = data.rfind(",") # search from end
i_comma3:int = data.rfind(",", 0, i_comma4-1) # search for a comma from right, starting at 0 and ending at the last comma (or right before it)
# i_linebreak:int = data.find("\r\n")

# extract

ReceivedMessage = data
address = int(data[i_equal + 1:i_comma1])
length = int(data[i_comma1 + 1:i_comma2])
msg = data[i_comma2 + 1:i_comma3] RSSI = int(data[i_comma3 + 1:i_comma4])
#SNR = int(data[i_comma4 + 1:i_linebreak])

except Exception as e:
raise Exception("Unable to parse line '" + str(data) + "' as a ReceivedMessage! Exception message: " + str(e))

# String parsing modified from ChatGPT code

pairs = msg.split(";") # Split the string into key-value pairs
for pair in pairs:
if ":" in pair:
key, value = pair.split(":") # Separate key and value
# Try to convert value to int or float if possible

if value.replace(".", "", 1).isdigit():
value = float(value) if "." in value else int(value)
result[key] = value
return result

# Example usage

#data_string = "Led=1;Temp=77;Light=0.85" #parsed_data =

parse_sensor_data(data_string) #print(parsed_data)

i = 0
recieved = False

while True:
data = uart.read()

if data is not None:
led.value = True
data_string = ''.join([chr(b) for b in data]) print(data_string, end="")
parsed = parse_sensor_data(data_string) print(parsed)
lcd.write("Recieved! \n #: " + str(i)) led.value = False
recived = True
i += 1

else:
if recieved == False:
lcd.clear()
lcd.write("Waiting...")
print("waiting")
time.sleep(0.05)

else:
time.sleep(0.05)

Website host code
- Written primarily by ChatGPT, with formatting and order changes by me // WSmDNSGraph
// Ben Arnett
// 05/18/2025

// PRIMARILY WRITTEN BY CHATGPT // small syntax changes and formatting by B. Arnett

#include <WiFi.h>

#include <time.h>

#include <WebServer.h>

#include "secrets.h"

// Add a secrets.h file to store WiFi login // otherwise edit params. under setup() > WiFi.begin()
#include <DNSServer.h>

#include <ESPmDNS.h>

#include <Ticker.h>

#define LORA_RX 17

#define LORA_TX 16

String loraBuffer = "";
int lastRSSI = -100;

#define MAX_RECORDS 60 // assuming ~1 data point every 30 seconds

struct WeatherData {
int aqi;
float temperature;
float humidity;
int pressure;
int altitude;
float light;
float lightperc;
String timestamp;
time_t epoch;
int rssi;
};

String latestData = "";
float latestTemp = 0.0;

const int maxDataPoints = 20;
float temperatureData[maxDataPoints]; int tempIndex = 0;

String getContentType(String filename) {
if (filename.endsWith(".htm") || filename.endsWith(".html")) return "text/html"; else if (filename.endsWith(".css")) return "text/css";
else if (filename.endsWith(".js")) return "application/javascript";
return "text/plain";
}

WeatherData dataBuffer[MAX_RECORDS]; int bufferSize = 0;
WebServer server(80);
bool isCaptivePortal = false;

DNSServer dnsServer;
const byte DNS_PORT = 53;
const char* localHostname = "loraweather";

String getLocalTimeString() {
struct tm timeinfo;
if (!getLocalTime(&timeinfo)) { return "TIME ERROR";
}
char timeStr[20];
strftime(timeStr, sizeof(timeStr), "%Y-%m-%d %H:%M:%S", &timeinfo);
return String(timeStr);
}

void readLoRaData() {
while (Serial1.available()) { char c = Serial1.read();
if (c == '\n') {
loraBuffer.trim();
if (loraBuffer.length() > 0) { parseLoRaMessage(loraBuffer); }
loraBuffer = "";
} else {
loraBuffer += c;

}
}
}

void parseLoRaMessage(String message) { if (message.startsWith("+RCV=")) {
message = message.substring(5);
int comma1 = message.indexOf(',');
int comma2 = message.indexOf(',', comma1 + 1);
int comma3 = message.indexOf(',', comma2 + 1);
int comma4 = message.indexOf(',', comma3 + 1);

String sender = message.substring(0, comma1);
String length = message.substring(comma1 + 1, comma2);
String payload = message.substring(comma2 + 1, comma3);
String SNR = message.substring(comma3 + 1, comma4);
String RSSI = message.substring(comma4 + 1);

lastRSSI = RSSI.toInt();

Serial.println("=== LoRa Message Received ===");
Serial.println("From: " + sender); Serial.println("Length: " + length); Serial.println("Payload: " + payload); Serial.println("SNR: " + SNR); Serial.println("RSSI: " + RSSI);

Serial.println("========================= =====");

if (payload.startsWith("AQI:")) {
String timestamp = getLocalTimeString(); WeatherData w =
parseWeatherString(payload, timestamp); w.rssi = RSSI.toInt();

struct tm timeinfo;
getLocalTime(&timeinfo);

w.epoch = mktime(&timeinfo);

temperatureData[tempIndex] = w.temperature;
tempIndex = (tempIndex + 1) % maxDataPoints;

if (bufferSize < MAX_RECORDS) { dataBuffer[bufferSize++] = w;
} else {
for (int i = 1; i < MAX_RECORDS; i++) { dataBuffer[i - 1] = dataBuffer[i];
}
dataBuffer[MAX_RECORDS - 1] = w; }

Serial.println("---- Weather Data ----"); Serial.println("Time: " + w.timestamp); Serial.print("AQI: "); Serial.println(w.aqi); Serial.print("Temp: ");
Serial.println(w.temperature); Serial.print("Humidity: "); Serial.println(w.humidity); Serial.print("Pressure: "); Serial.println(w.pressure); Serial.print("Altitude: "); Serial.println(w.altitude); Serial.print("Light Level: "); Serial.println(w.light);

printHourlyAverages();
}
} else {
Serial.println("Other LoRa Response: " + message);
}
}

WeatherData parseWeatherString(String input, String timestamp) {
WeatherData data;
input.trim();
data.timestamp = timestamp;

int start = 0;
while (start < input.length()) { int sep = input.indexOf(':', start);

int end = input.indexOf(';', sep);
if (end == -1) end = input.length();

String key = input.substring(start, sep); String value = input.substring(sep + 1, end);

if (key == "AQI") data.aqi = value.toInt(); else if (key == "T") data.temperature = value.toFloat();
else if (key == "RH") data.humidity = value.toFloat();
else if (key == "hPa") data.pressure = value.toInt();
else if (key == "Alt") data.altitude = value.toInt();
else if (key == "L") data.light = value.toFloat();

data.lightperc = data.light * 30.77; start = end + 1;
}

return data;
}

String getAveragesHTML() { time_t now;
struct tm timeinfo;
getLocalTime(&timeinfo);
now = mktime(&timeinfo);

float sumAQI = 0, sumTemp = 0, sumHum = 0, sumPress = 0, sumAlt = 0, sumLight = 0, sumLightperc = 0;
int count = 0;

for (int i = 0; i < bufferSize; i++) {
if (difftime(now, dataBuffer[i].epoch) <= 3600) {
sumAQI += dataBuffer[i].aqi;
sumTemp += dataBuffer[i].temperature; sumHum += dataBuffer[i].humidity; sumPress += dataBuffer[i].pressure; sumAlt += dataBuffer[i].altitude; sumLight += dataBuffer[i].light; sumLightperc += dataBuffer[i].lightperc; count++;

}
}

if (count == 0) return "<p>No recent data to average.</p>";

String html =
"<table><tr><th>Metric</th><th>Average</th>< /tr>";
html += "<tr><td>AQI</td><td>" + String(sumAQI / count, 1) + "</td></tr>";
html += "<tr><td>Temperature (°C)</td><td>" + String(sumTemp / count, 1) + "</td></tr>"; html += "<tr><td>Humidity (%)</td><td>" + String(sumHum / count, 1) + "</td></tr>"; html += "<tr><td>Pressure (hPa)</td><td>" + String(sumPress / count, 1) + "</td></tr>"; html += "<tr><td>Altitude (m)</td><td>" + String(sumAlt / count, 1) + "</td></tr>";
html += "<tr><td>Light (V)</td><td>" + String(sumLight / count, 2) + "</td></tr>"; html += "<tr><td>Light (%)</td><td>" + String(sumLightperc / count, 1) + "</td></tr>"; html += "</table>";

return html;
}

void printHourlyAverages() { time_t now;
struct tm timeinfo;
if (getLocalTime(&timeinfo)) {
now = mktime(&timeinfo);
} else {
Serial.println("Failed to get time");
return;
}

float sumAQI = 0, sumTemp = 0, sumHum = 0, sumPress = 0, sumAlt = 0, sumLight = 0, sumLightperc = 0;
int count = 0;

for (int i = 0; i < bufferSize; i++) {
if (difftime(now, dataBuffer[i].epoch) <= 3600) {
sumAQI += dataBuffer[i].aqi;

sumTemp += dataBuffer[i].temperature; sumHum += dataBuffer[i].humidity; sumPress += dataBuffer[i].pressure; sumAlt += dataBuffer[i].altitude; sumLight += dataBuffer[i].light; sumLightperc += dataBuffer[i].lightperc; count++;
}
}

if (count == 0) {
Serial.println("No recent data to average."); return;
}

Serial.println("---- Hourly Averages ----"); Serial.printf("Avg AQI: %.1f\n", sumAQI / count);
Serial.printf("Avg Temp (°C): %.1f\n",
sumTemp / count);
Serial.printf("Avg RH (%%): %.1f\n", sumHum / count);
Serial.printf("Avg Pressure (hPa): %.1f\n", sumPress / count);
Serial.printf("Avg Altitude (m): %.1f\n", sumAlt / count);
Serial.printf("Avg Light (V): %.2f\n", sumLight / count);
Serial.printf("Avg Light (%): %.1f\n", sumLightperc / count);
}

String getSignalStrengthBar(int rssi) {
int percentage = constrain(map(rssi, -100, -40, 0, 100), 0, 100);
String color = (rssi > -70) ? "green" : (rssi > -90) ? "orange" : "red";
String html = "<div style='border:1px solid #ccc;width:100%;height:20px;'><div style='height:100%;width:" + String(percentage) + "%;background-color:" + color + "'></div></div>";
return html;
}

void handleRoot() {

String html = "<!DOCTYPE
html><html><head><meta charset='UTF-8'>"; html += "<meta name='viewport' content='width=device-width, initial-scale=1.0'>";
html += "<title>Weather Dashboard</title>"; html +=
"<style>body{font-family:sans-serif;padding:2e m;}table{border-collapse:collapse;}td,th{padding :0.5em;border:1px solid #ccc;}</style>";
html += "</head><body>";
html += "<h1>Latest Weather Data</h1>";

if (bufferSize > 0) {
WeatherData latest = dataBuffer[bufferSize -1];
html +=
"<table><tr><th>Metric</th><th>Value</th></tr >";
html += "<tr><td>AQI</td><td>" + String(latest.aqi) + "</td></tr>";
html += "<tr><td>Temperature (°C)</td><td>" + String(latest.temperature) + "</td></tr>"; html += "<tr><td>Humidity (%)</td><td>" + String(latest.humidity) + "</td></tr>";
html += "<tr><td>Pressure (hPa)</td><td>" + String(latest.pressure) + "</td></tr>";
html += "<tr><td>Altitude (m)</td><td>" + String(latest.altitude) + "</td></tr>";
html += "<tr><td>Light (V)</td><td>" + String(latest.light) + "</td></tr>";
html += "<tr><td>Light (%)</td><td>" + String(latest.lightperc) + "</td></tr>"; html += "<tr><td>LoRa RSSI (dBm)</td><td>" + String(latest.rssi) + "</td></tr>";
html += "<tr><td>Timestamp</td><td>" + latest.timestamp + "</td></tr>";
html += "</table>";
} else {
html += "<p>No data available.</p>";
}

html += "<h2>LoRa Signal Strength</h2>"; html += "<p>RSSI: " + String(lastRSSI) + " dBm</p>";
html += getSignalStrengthBar(lastRSSI);

html += "<p><small><strong>-70 dBm or
higher:</strong> Excellent | <strong>-90 dBm to
-70 dBm:</strong> Okay | <strong>-100 dBm to
-90 dBm:</strong> Weak</small></p>";

html += "<h2>Hourly Averages</h2>";
html += getAveragesHTML();
html += "<p><em>Page refreshes every 60 seconds</em></p>";
html +=
"<script>setTimeout(()=>location.reload(),60000 );</script>";
html += "</body></html>";

String graphs = R"rawliteral(
<title>Weather Dashboard</title>
<script
src="https://cdn.jsdelivr.net/npm/chart.js"></scri pt>
<style>
body { font-family: sans-serif; text-align: center; margin: 20px; }
canvas { max-width: 600px; margin: auto; } </style>
</head>
<body>
<h1>LoRa Weather Dashboard</h1> <div id="dataDisplay">Loading latest data...</div>
<canvas id="tempChart" width="600" height="300"></canvas>

<script>
let tempChart;

async function fetchData() { const res = await fetch('/data');
const json = await res.json();

document.getElementById('dataDisplay').innerT ext = json.latest;

if (!tempChart) {
const ctx =
document.getElementById('tempChart').getCont ext('2d');

tempChart = new Chart(ctx, {
type: 'line',
data: {
labels: json.history.map((_, i) => i + 1),
datasets: [{
label: 'Temperature (°C)',
data: json.history,
borderColor: 'orange',
fill: false
}]
},
options: {
responsive: true,
scales: {
y: { beginAtZero: true }
}
}
});
} else {
tempChart.data.labels =
json.history.map((_, i) => i + 1); tempChart.data.datasets[0].data = json.history;
tempChart.update();
}
}

setInterval(fetchData, 2000); fetchData();
</script>
</body>
</html>
)rawliteral";
html += graphs;
server.send(200, "text/html", html); }

void handleDataJson() {
String json = "{";
json += "\"latest\":\"" + latestData + "\","; json += "\"history\":[";
for (int i = 0; i < maxDataPoints; i++) {
if (i > 0) json += ",";
json += String(temperatureData[(tempIndex +
i) % maxDataPoints]);
}

json += "]}";
server.send(200, "application/json", json); }

void setup() {
Serial.begin(115200);
Serial1.begin(115200, SERIAL_8N1, LORA_RX, LORA_TX);
Serial.println("LoRa Parser Ready");

// Before WiFi.begin()
WiFi.mode(WIFI_AP_STA); // allow AP and STA mode together
WiFi.setHostname(localHostname); // for mDNS when connected to other networks

// Start WiFi AP
WiFi.softAP("WeatherNode", "weather123");

// Start DNS redirect for captive portal dnsServer.start(DNS_PORT, "*", WiFi.softAPIP());

WiFi.begin(WIFI_SSID, WIFI_PASS); Serial.print("Connecting to WiFi");
unsigned long startAttempt = millis();
while (WiFi.status() != WL_CONNECTED && millis() - startAttempt < 10000) {
delay(500);
Serial.print(".");
}

if (WiFi.status() == WL_CONNECTED) { Serial.println("\nConnected to WiFi!"); Serial.print("Web server IP address: "); Serial.println(WiFi.localIP());
if (MDNS.begin(localHostname)) { Serial.println("mDNS responder started"); Serial.print("You can access via http://"); Serial.print(localHostname); Serial.println(".local");
} else {
Serial.println("Error setting up MDNS"); }

isCaptivePortal = false;
} else {
Serial.println("\nWiFi failed. Starting Access Point...");
isCaptivePortal = true;
WiFi.softAP("WeatherNode", "weather1234"); IPAddress AP_IP = WiFi.softAPIP(); Serial.print("AP IP address: "); Serial.println(AP_IP);
}

configTzTime("PST8PDT,M3.2.0,M11.1.0", "pool.ntp.org");

server.on("/", handleRoot); server.on("/data", handleDataJson); server.begin();
Serial.println("Web server started.");

server.onNotFound([]() {
server.sendHeader("Location", "/", true); server.send(302, "text/plain", "");
});
}

void loop() {
readLoRaData();

server.handleClient();
dnsServer.processNextRequest(); if (Serial.available()) {
Serial1.write(Serial.read());
}
}

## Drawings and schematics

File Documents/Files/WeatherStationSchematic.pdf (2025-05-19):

## Pi Pico 2

## Voltaic Solar Panel

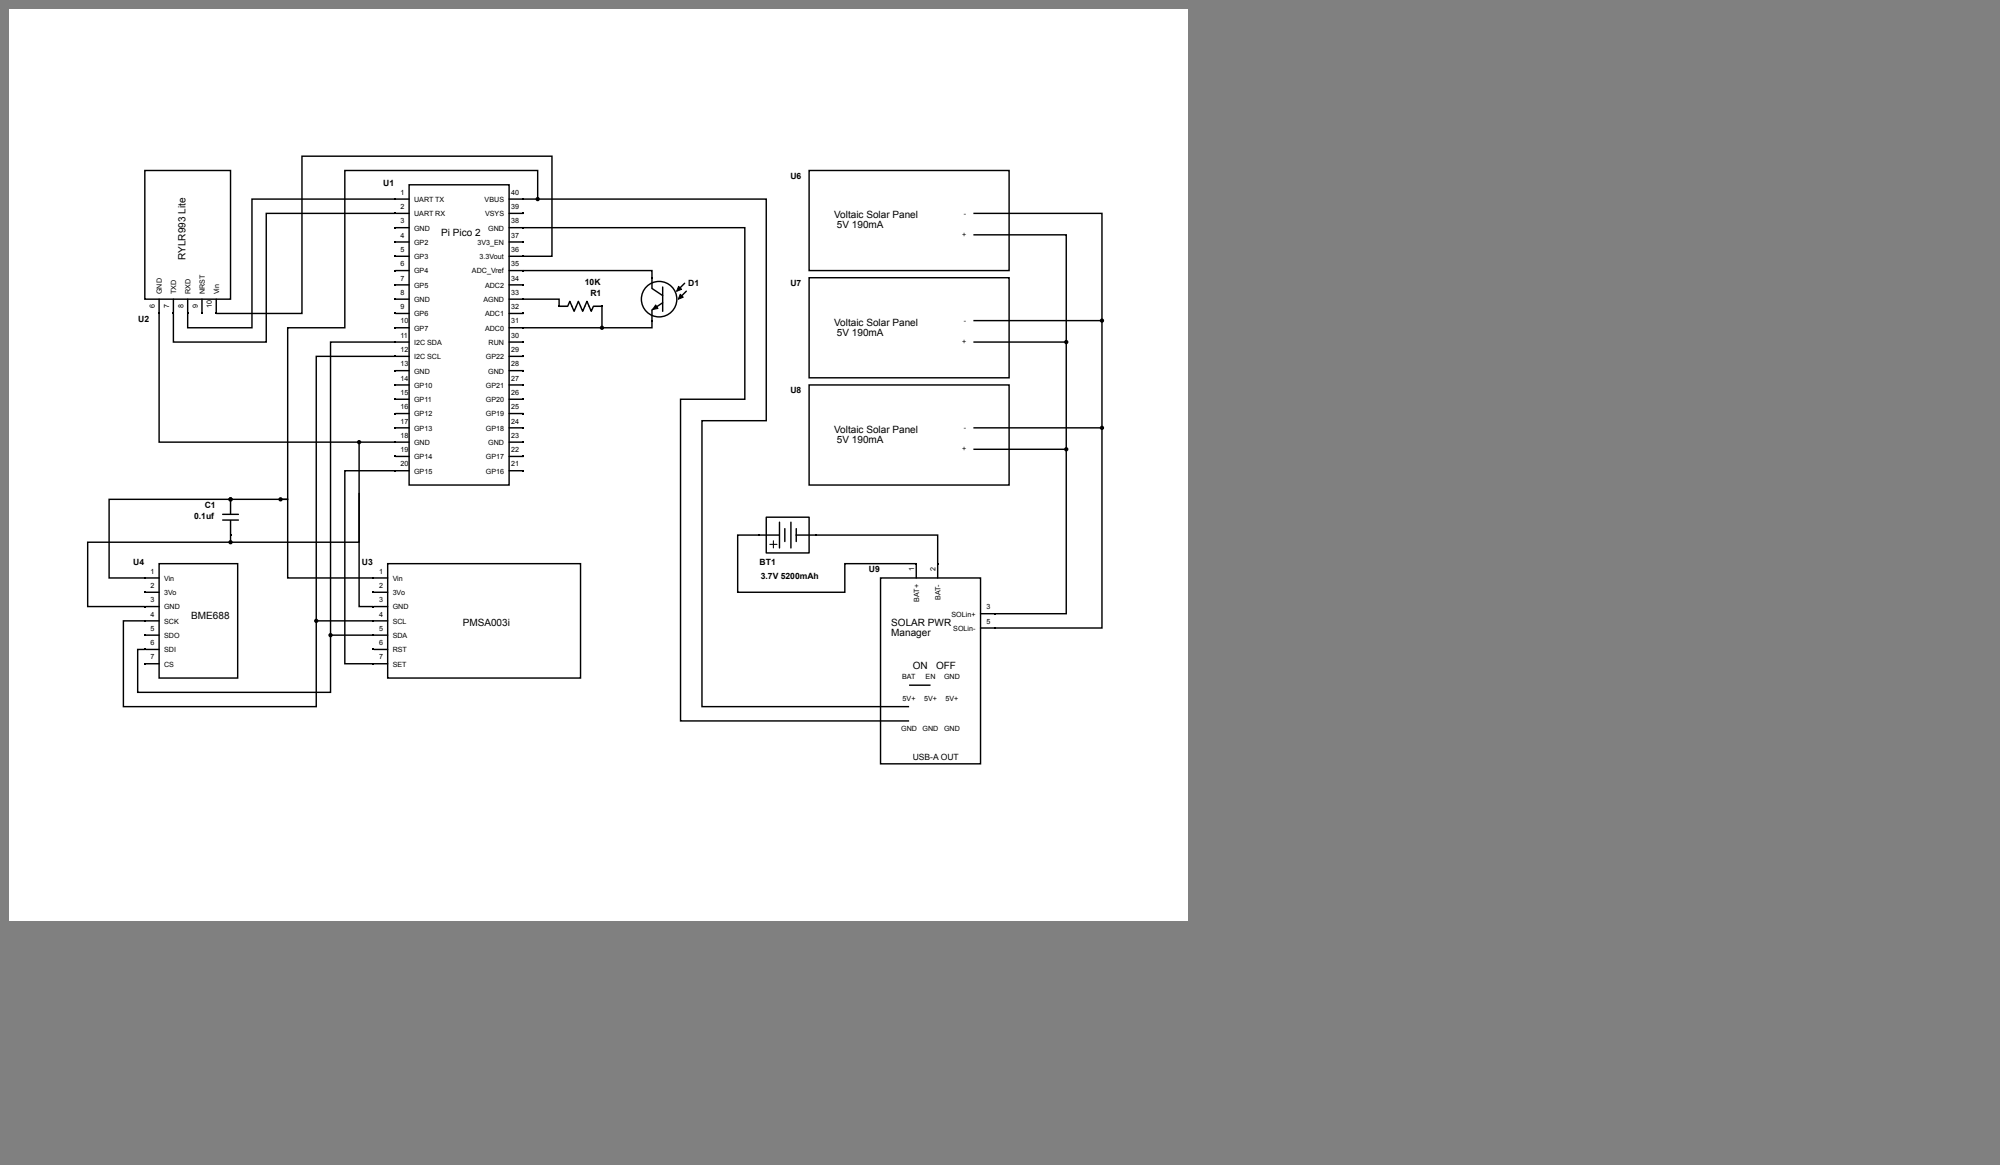
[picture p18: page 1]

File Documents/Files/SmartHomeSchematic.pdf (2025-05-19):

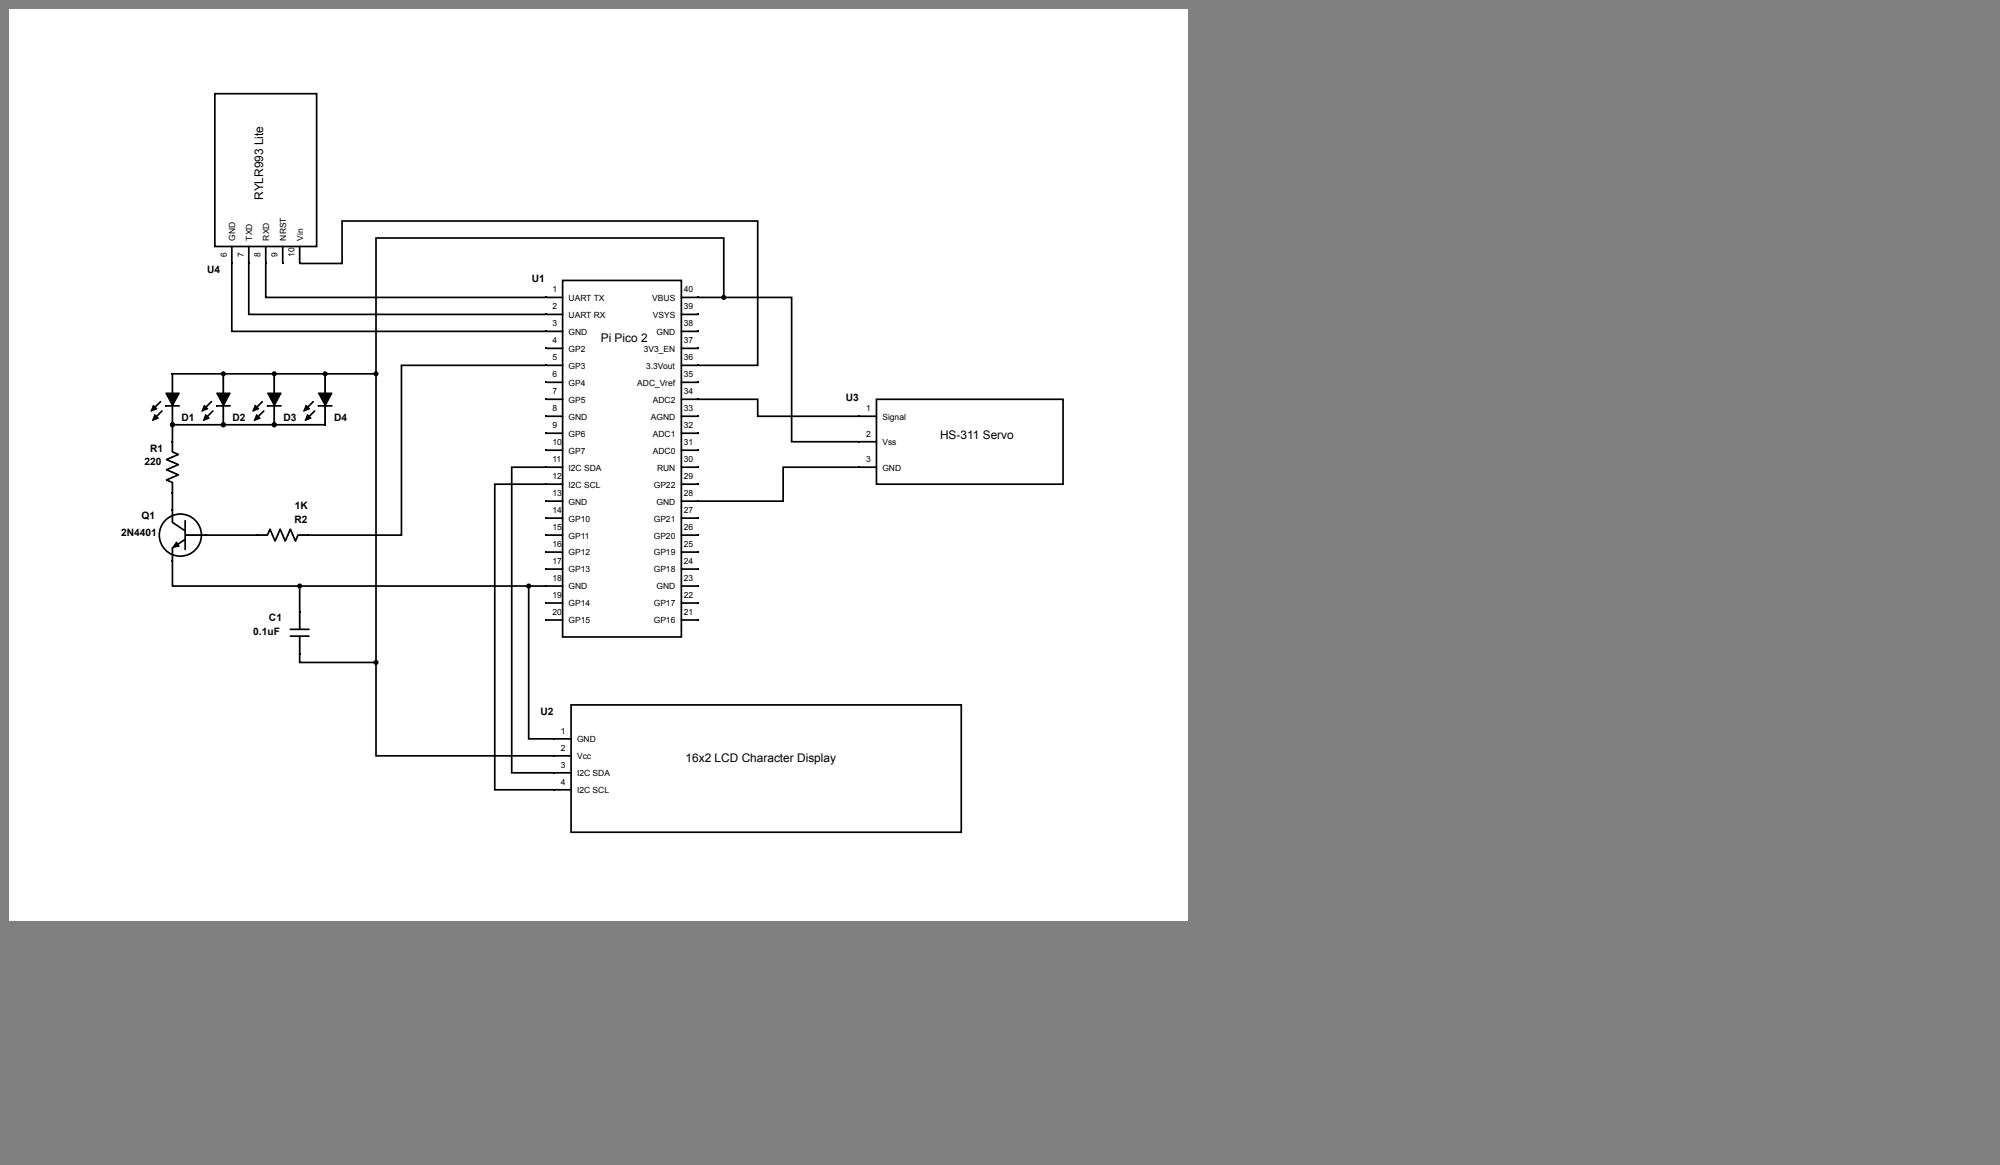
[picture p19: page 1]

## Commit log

2025-05-18 added cad, circuitpython code
    [AHSide.3mf, ActBase.3mf, CHLid.3mf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]
2025-05-19 added ArduinoIDE code
2025-05-19 added ESP32C6 website code, pics
2025-05-19 added test stl for github view
    [Lora Station Parts List-2.xlsx, WSAssembled.stl, XiaoBody.3mf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]
2025-05-19 added stl of Smart home
2025-05-19 fixed model home assembled stl
    [ModelHouseAssembled.stl]
2025-05-19 changed stl location
    [ModelHouseAssembled.stl]
2025-05-19 added sample secrets.h file
2025-05-19 Changed organization
    [AHSide.3mf, ActBase.3mf, CHLid.3mf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]
2025-05-19 added schematics
2025-05-19 added documentation pdfs, powerpoint
